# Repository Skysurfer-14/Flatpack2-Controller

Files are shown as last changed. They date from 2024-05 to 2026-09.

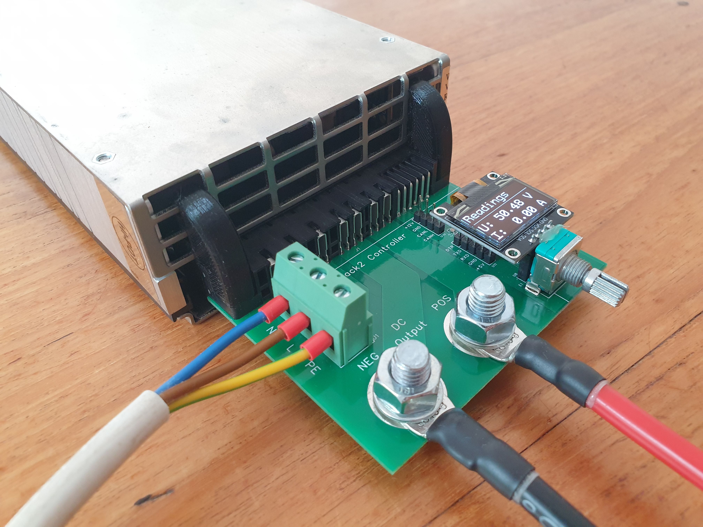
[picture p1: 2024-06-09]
docs/flatpack2-controller.jpg

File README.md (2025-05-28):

## Flatpack2 Controller ##
Connection board with controller, display and rotary encoder for controlling an Eltek Flatpack2 HE 48V/3000W power supply.
The Arduino program of the controller is maintained in this repository. Extensions and improvements are welcome!
flatpack2-controller
### Quick guide ###
- voltage and current are displayed after switching on (readings)
- to protect the OLED display, it is switched off after 60s if the rotary encoder is not used. It can be switched on again by pressing the Rotary Encoder.
- briefly pressing the Rotary Encoder switches the OLED display to the settings for the voltage. Turning the rotary encoder increases or decreases the voltage. A short press switches to the settings for the current. If the rotary encoder is pressed and held, the set value is also written to the non-volatile memory of the controller. 
- in the settings for the current, the maximum current can be increased or decreased by turning the rotary encoder. A short press switches to the readings. If the rotary encoder is pressed and held, the set value is also written to the non-volatile memory of the controller.

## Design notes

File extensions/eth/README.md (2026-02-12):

## **1. nano_skript.txt – Arduino Nano Controller**

Dieses Programm läuft auf einem **Arduino Nano** und dient als **Steuereinheit für ein Flatpack2-Netzteil** (PSU = Power Supply Unit). Der Nano ist das zentrale Steuergerät mit folgenden Hauptaufgaben:

### Kernfunktionen:
- **Lokale Bedienung**: Über einen Drehencoder (Rotary Encoder) und ein OLED-Display können Spannung und Strom direkt am Gerät eingestellt werden
- **I2C-Kommunikation mit PSU**: Der Nano kommuniziert über I2C mit dem Flatpack2-Netzteil, um:
  - Sollwerte (Spannung, Strom) zu setzen
  - Messwerte (aktuelle Spannung, Strom, Temperaturen) auszulesen
  - Das Netzteil ein-/auszuschalten
  - Statuswerte zu überwachen

- **UART-Kommunikation**: Der Nano fungiert als "Slave" und kann über die serielle Schnittstelle (38400 Baud) von einem übergeordneten System (WT32) ferngesteuert werden
- **Dual-Modus**: Das System kann sowohl **autonom** (nur mit Nano) als auch **ferngesteuert** (über WT32) betrieben werden. Das Display zeigt an, ob ein Master-Gerät (z.B. "Cerbo") verbunden ist

### Besondere Features:
- Speicherung der Einstellungen im EEPROM
- Heartbeat-Mechanismus zur Verbindungsüberwachung
- CRC-gesicherte Kommunikation
- Display-Timeout zur Schonung

---

## **2. wt32-eth-skript.txt – WT32-ETH01 Webserver**

Dieses Programm läuft auf einem **WT32-ETH01** (ESP32 mit Ethernet) und dient als **Netzwerk-Gateway und Webinterface** für das Flatpack2-System:

### Kernfunktionen:
- **Web-Interface**: Stellt ein modernes HTML-Dashboard bereit, über das das Netzteil per Browser gesteuert werden kann
- **UART-Master**: Kommuniziert über Serial2 mit dem Nano und sendet Befehle (Spannung/Strom setzen, Ein/Aus schalten)
- **Ethernet/WiFi-Anbindung**: Ermöglicht Fernzugriff auf das System (feste IP: 192.168.1.234)
- **OTA-Updates**: Das Programm kann über das Netzwerk aktualisiert werden (Over-The-Air)

### API-Endpunkte:
- `/values` – Liefert aktuelle Messwerte und Status als JSON
- `/set_voltage?voltage=XX` – Setzt die Sollspannung
- `/set_current?current=XX` – Setzt den Sollstrom
- `/cmd?c=on|off` – Schaltet das Netzteil ein/aus

### Statusüberwachung:
- Erkennt, ob der Nano verbunden ist (Timeout: 15 Sekunden)
- Zeigt Gesundheitsstatus an (OK / WARN / FAULT)
- Überwacht Temperaturen und Statusbits des Netzteils

---

## **Zusammenspiel der beiden Systeme:**

```
[Flatpack2 PSU] ←I2C→ [Arduino Nano] ←UART→ [WT32-ETH01] ←Ethernet/WiFi→ [Browser/Victron Cerbo]
                         ↓
                  [Drehencoder + OLED]
```

Der **Nano** ist die direkte Hardwareschnittstelle zum Netzteil und kann eigenständig arbeiten. Der **WT32** erweitert das System um Netzwerkfunktionen und ein komfortables Webinterface, bleibt aber optional – der Nano funktioniert auch ohne ihn.

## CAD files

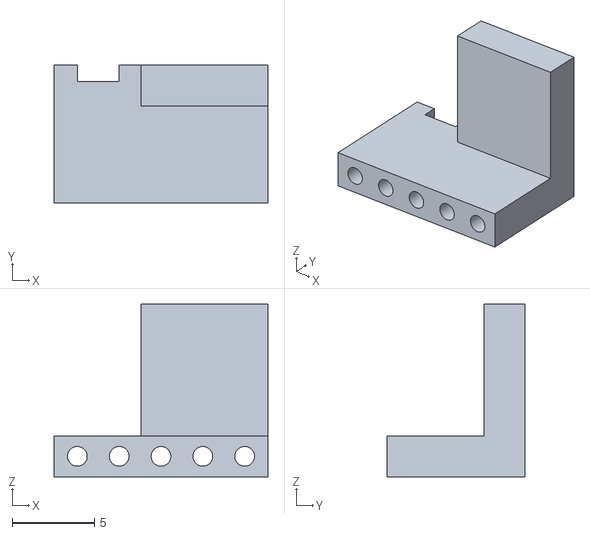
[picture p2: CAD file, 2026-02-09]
mechanic/DisplaySupport.stl
13.0 x 8.40 x 10.5

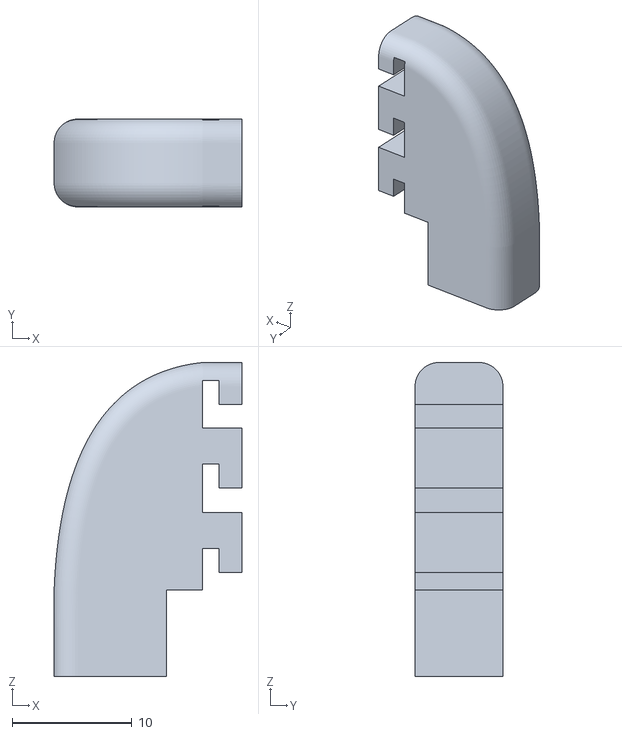
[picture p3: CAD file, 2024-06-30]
mechanic/Halteklammer Flatpack v2.stl
15.7 x 7.35 x 26.2

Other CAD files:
mechanic/DisplaySupport.f3d
mechanic/Halteklammer Flatpack v2.f3d

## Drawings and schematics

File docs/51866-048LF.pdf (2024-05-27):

PDS: Rev :B | STATUS:Released | Printed: Aug 14, 2013 Datasheet.Live

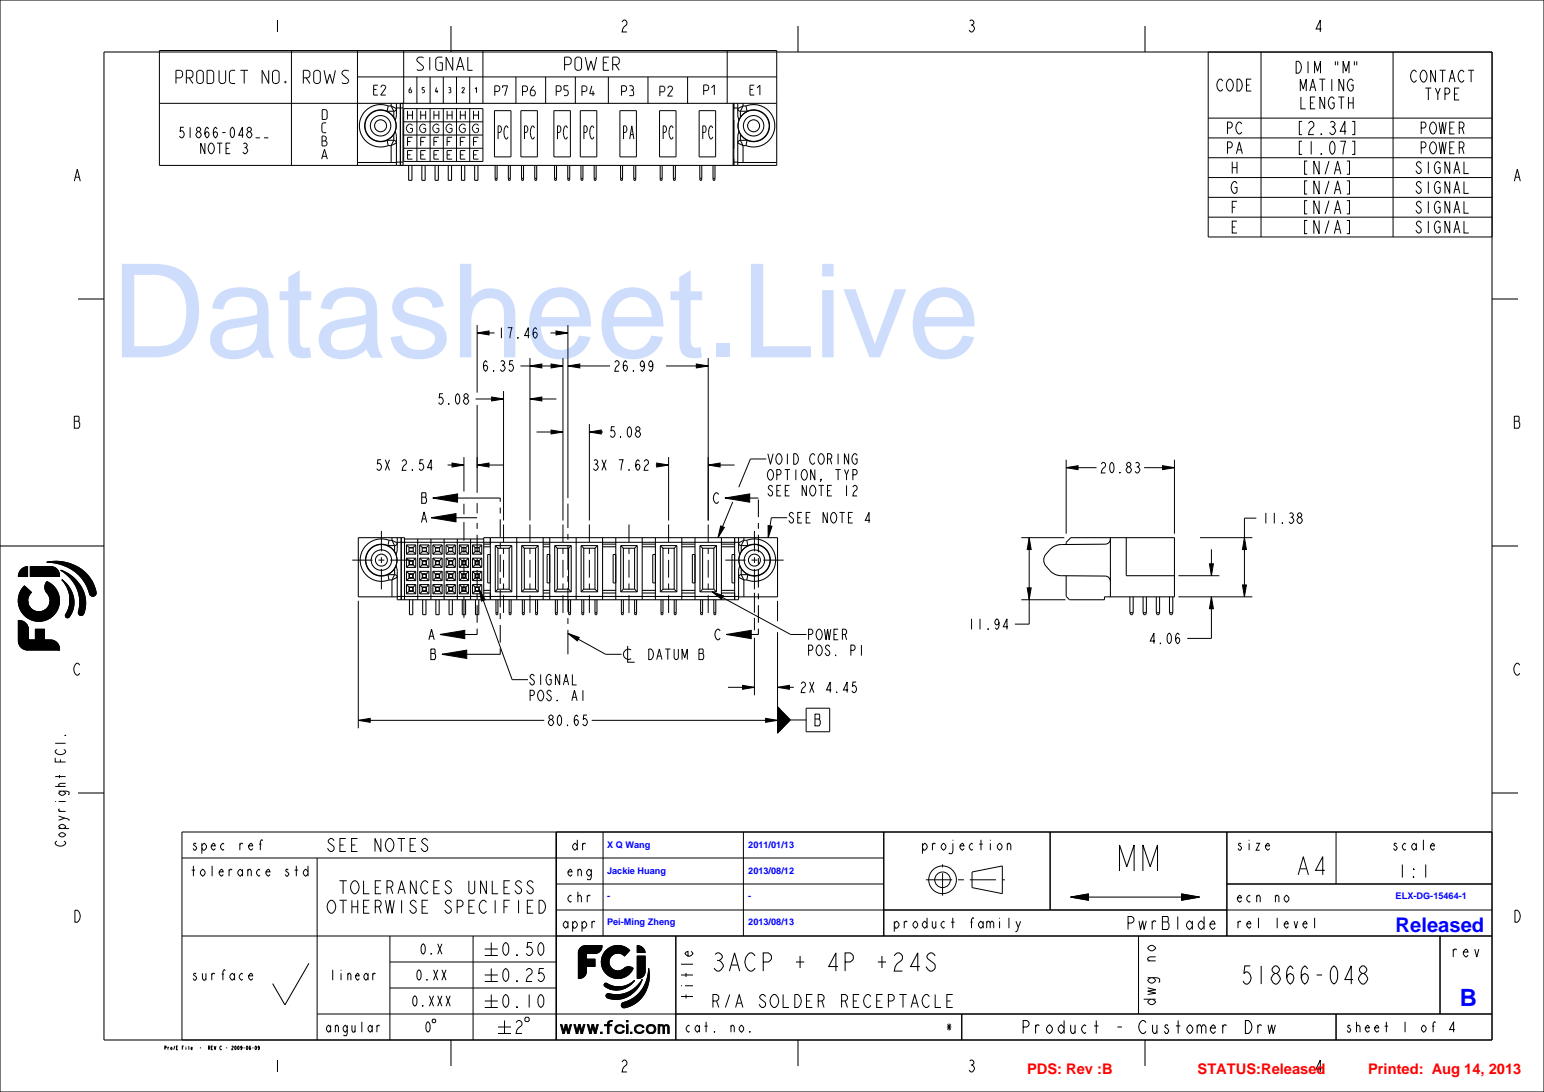
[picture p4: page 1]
Jackie Huang; X Q Wang; ELX-DG-15464-1 Released

Pei-Ming Zheng

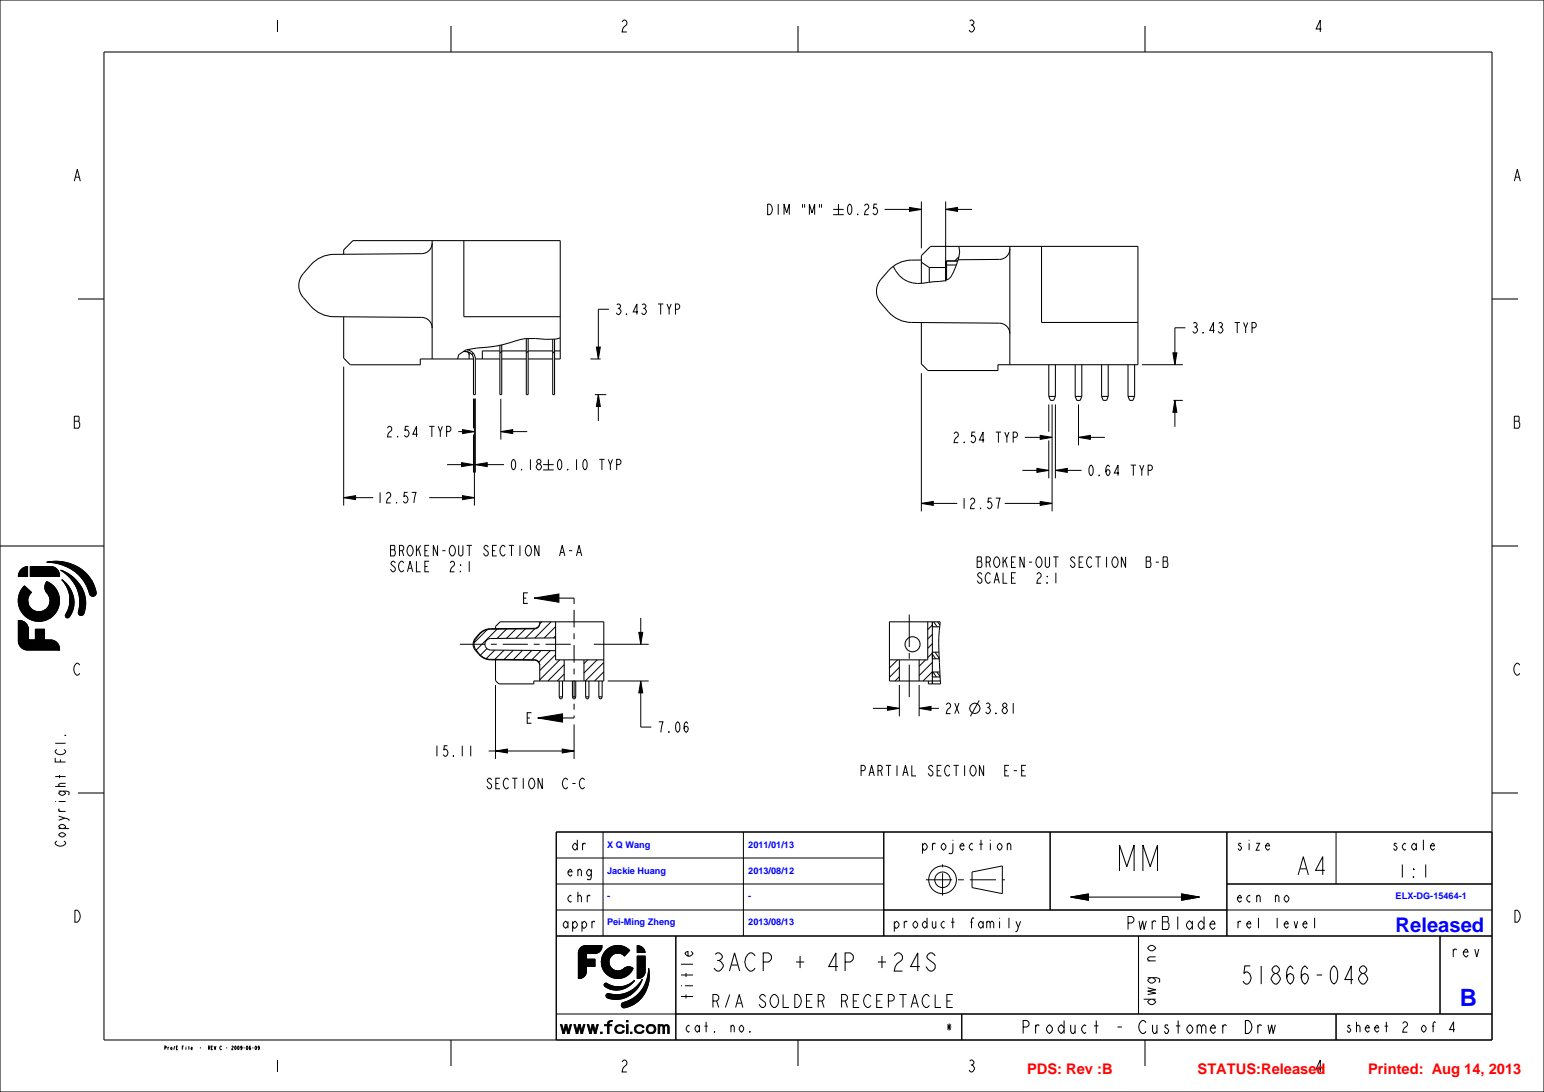
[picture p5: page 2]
Jackie Huang; X Q Wang; ELX-DG-15464-1 Released; PDS: Rev :B; STATUS:Released; Printed: Aug 14, 2013

Pei-Ming Zheng

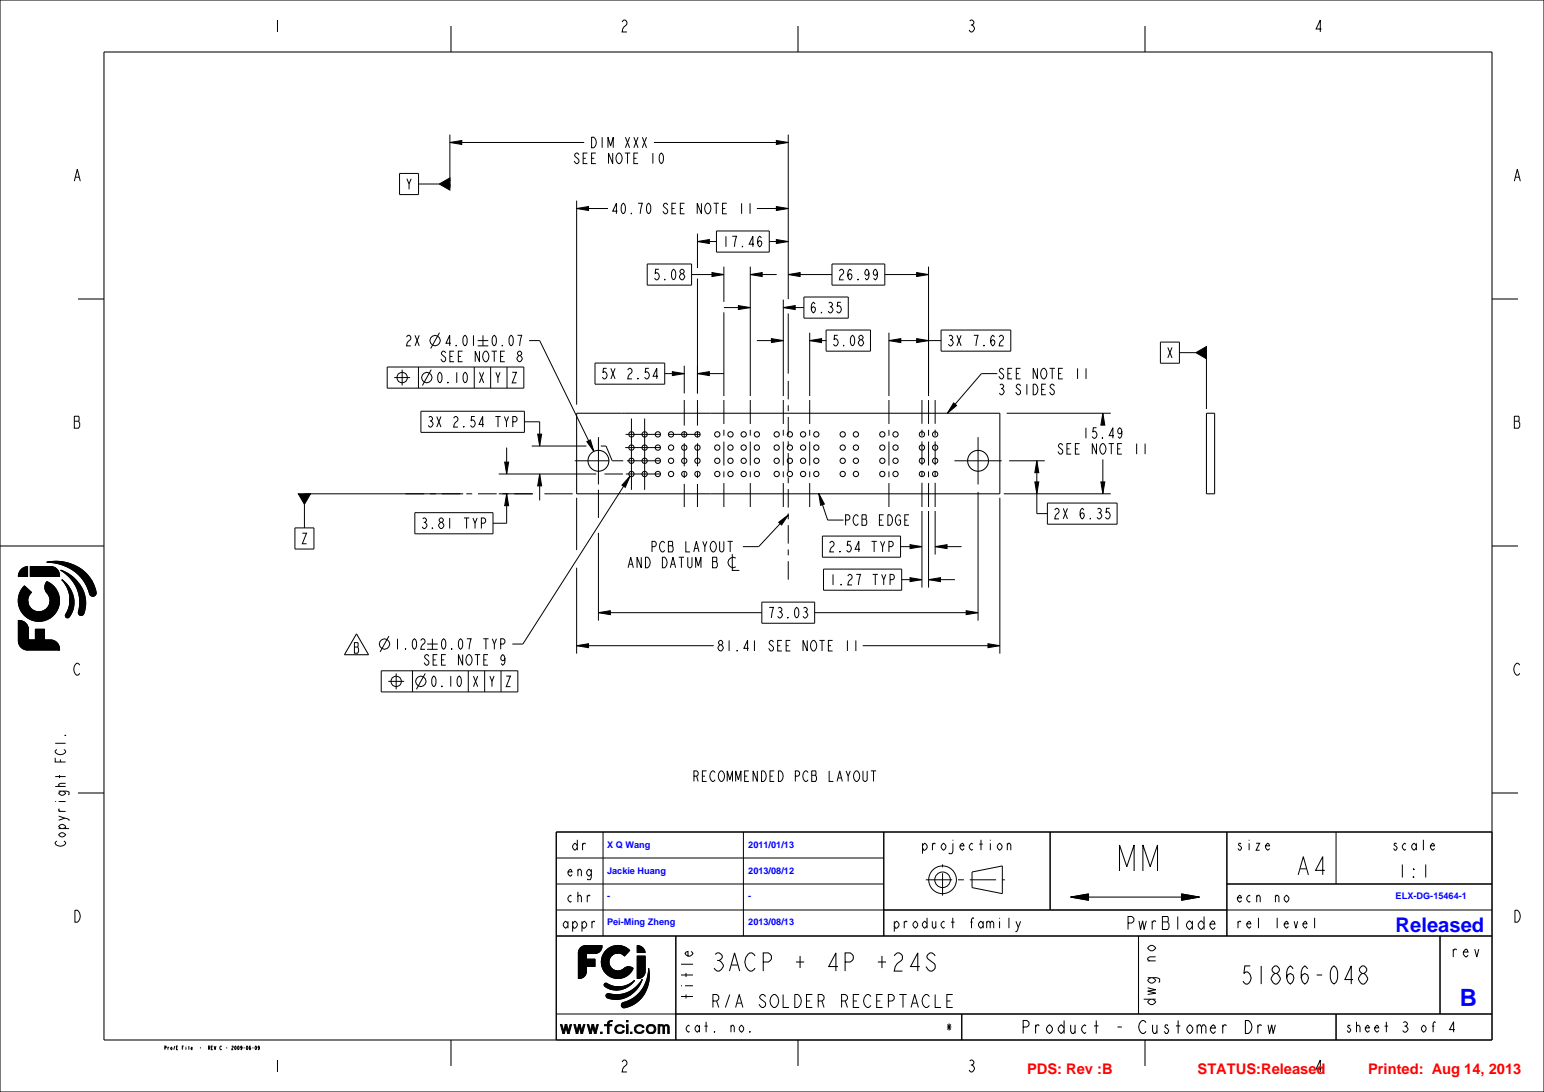
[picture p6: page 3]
Jackie Huang; X Q Wang; ELX-DG-15464-1 Released

Pei-Ming Zheng

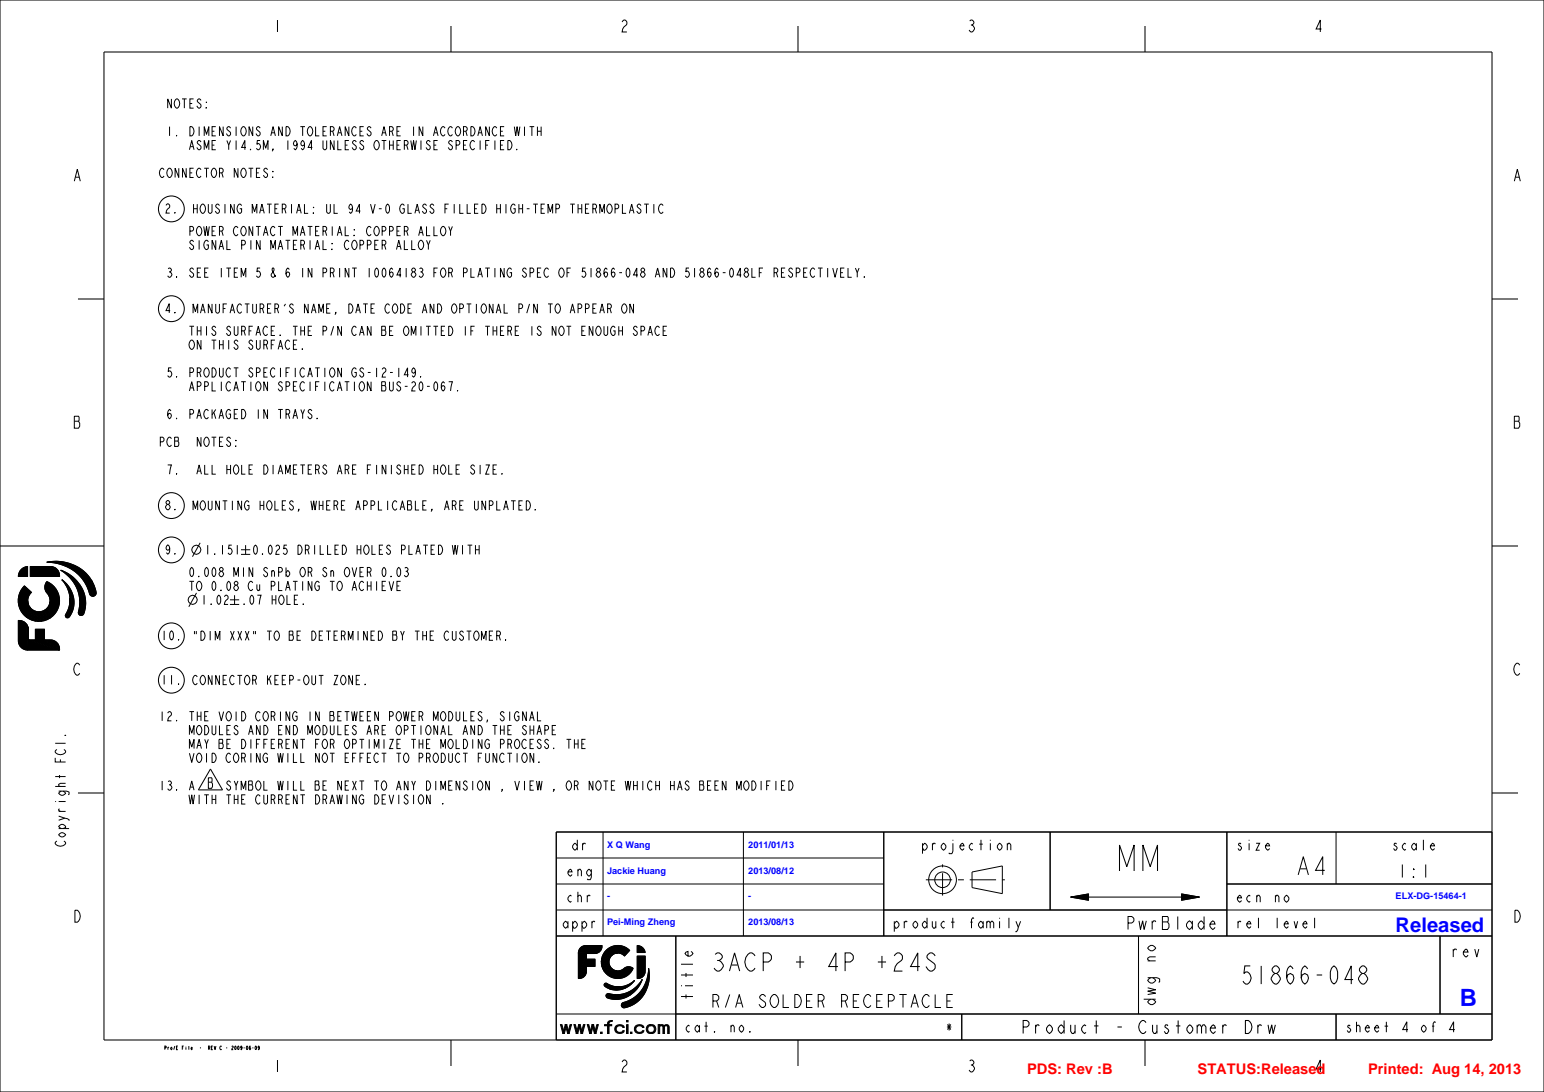
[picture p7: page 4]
Jackie Huang; X Q Wang; ELX-DG-15464-1 Released

Pei-Ming Zheng

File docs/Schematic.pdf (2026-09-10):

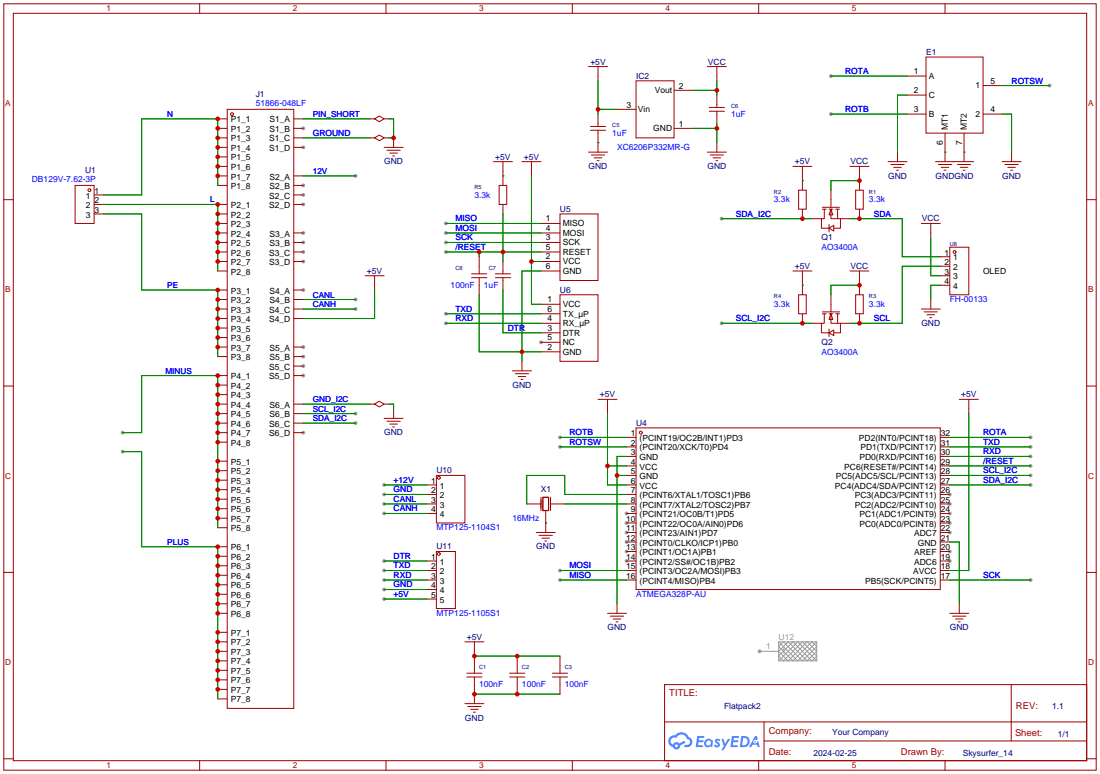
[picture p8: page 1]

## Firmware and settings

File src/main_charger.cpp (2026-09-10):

#include <Arduino.h>
#include <RotaryEncoder.h>
#include <Wire.h>
#include <SPI.h>
#include <U8g2lib.h>
#include <EEPROM.h>

/*
Todo:
- COMM_STAT vom PSU hat immer Bit1 gesetzt, sollte aber nicht gesetzt sein. Evtl. CRC8-Fehler?

*/

// The complete list is available here: https://github.com/olikraus/u8g2/wiki/u8g2setupcpp
// Please update the pin numbers according to your setup. Use U8X8_PIN_NONE if the reset pin is not connected
U8G2_SSD1306_128X64_NONAME_2_HW_I2C u8g2(U8G2_R2, /* reset=*/ U8X8_PIN_NONE);

#define ROTA  2
#define ROTB  3
#define ROTSW 4

#define PSU_WRITE_ADDR  0x00
#define PSU_READ_ADDR   0x0F

// PSU RAM
// PSU Status, Offset 0x00
#define PSU_STATUS          0x00  // Read Only
#define PSU_STAT_DC_ON          0x0001  // 1 = DC/DC enabled
#define PSU_STAT_BOOST_OK       0x0002  // 1 = Boost Voltage OK
#define PSU_STAT_AC_OK          0x0004  // 1 = AC input voltage OK
#define PSU_STAT_HVSD           0x0008  // 1 = Output shut down due to hi-voltage
#define PSU_STAT_FAN_FAIL       0x0010  // 1 = Fan failure
#define PSU_STAT_INT_TEMP       0x0040  // 1 = Heatsink over temperature alarm
#define PSU_STAT_ILIM           0x0080  // 1 = Current limit
#define PSU_STAT_UV_ALARM       0x0100  // 1 = Output Voltage below UV alarm threshold
#define PSU_STAT_UVSD           0x0200  // 1 = Output shut down due to lo-voltage
#define PSU_STAT_DC_ENABLE      0x0800  // 1 = DC enable asserted
#define PSU_STAT_REMOTE_OFF     0x1000  // 1 = Shutdown due to I2C remote off command     
#define PSU_STAT_MOD_DISABLE    0x2000  // 1 = Shutdown due to MOD_DISABLE input  
#define PSU_STAT_SHORT_PIN      0x4000  // 1 = Shutdown due to short pin transition    

// PSU Command, Offset 0x02
#define PSU_COMMAND         0x02  // Write
#define PSU_CMD_ON              0x02  // 1 = Turn on Rectifier
#define PSU_CMD_OFF             0x04  // 1 = Turn off Rectifier
#define PSU_CMD_ALARM_ON        0x08  // 1 = Enable Latent DC Failure Alarm
#define PSU_CMD_ALARM_OFF       0x10  // 1 = Disable Latent DC Failure Alarm

#define PSU_LOCATION        0x03  // RO Number that identifies device location in a shelf. (Hi-Nibble = Group type Lo-Nibble = Lo-Nibble of I2C Address)
#define PSU_TEMP_SEC_OR     0x04  // RO Output OR-ing FET temperature in degrees C Range 0C to +116C, 255=short, +127=open
#define PSU_TEMP_SEC_DIODES 0x05  // RO DC/DC output diode temperature in degrees C Range 0C to +116C, 255=short, 127=open
#define PSU_MEASURE_VOUT    0x06  // RO Output Voltage in Volts x 100
#define PSU_MEASURE_IOUT    0x08  // RO Output Current in Amps x 100
#define PSU_SETPOINT_ILIMIT 0x0A  // RW Current Limit Set Point in Amps x 100
#define PSU_SETPOINT_VOUT   0x0C  // RW Output Voltage Set Point in Volts x 100
#define PSU_SETPOINT_HVSD   0x0E  // RW Unit level High Voltage Shut Down Set Point in Volts x 100
#define PSU_SETPOINT_FAN    0x10  // RO Fan period, 38 - Low, 27 – Med, 1B – High, read only

// PSU EEPROM
#define PSU_SERIAL_NUMBER   0x42  // RO uchar[12] Device serial number as an array of ASCII characters
#define PSU_MODEL_NUMBER    0x4E  // RO uchar[8] Device model number as an array of ASCII characters
#define PSU_VSET_DEFAULT    0x72  // RW Power-up value for voltage setpoint
#define PSU_ISET_DEFAULT    0x74  // RW Power-up default for current limit setpoint
#define PSU_HVSD_DEFAULT    0x76  // RW Power-up default for HVSD setpoint

#define DISPLAY_TIMEOUT     60000 // OLED Protection Timeout (ms)
#define PSU_VSET_MAX        5800  // Maximum Voltage Setting (Volt * 100)
#define PSU_VSET_MIN        4320  // Minimum Voltage Setting (Volt * 100)
#define PSU_V_RELOAD_DEFAULT 4800 // Default restart voltage (Volt * 100)
#define PSU_ISET_MAX        6250  // Maximum Current Setting (Ampere * 100)
#define PSU_ISET_MIN        0000  // Minimum Current Setting (Ampere * 100)
#define CV_CHARGING_TIMEOUT (30UL * 60UL * 1000UL)

// Charger defines
#define OC_CURRENT_FACTOR   2     // Threshold factor for OC-Error
#define OC_ERROR_ENABLED    0     // Enable OC-Error

// Prozessor-EEPROM
struct nonVolatileStruct
{
  uint16_t voltage;
  uint16_t current;
  uint16_t highvoltage;
  uint16_t reloadVoltage;
  uint8_t chargeMode;
};

nonVolatileStruct nonVolatile;

enum ChargeMode : uint8_t
{
  single_charge,
  cycle_charge
};

uint16_t actualReadVoltage = 0;
uint16_t actualReadCurrent = 0;
uint16_t actualSetVoltage = 0;
uint16_t actualSetCurrent = 0;

typedef enum {
  wait_for_battery,
  ramp_up,
  cc_charging,
  cv_charging,
  wait_for_reload,
  charging_done,
  wait_for_nobattery,
  oc_error,
  nc_error,
  setting_u,
  setting_i,
  setting_reload,
  setting_charge_mode,
  save_dialog,
  save
} State_type;

State_type state = wait_for_battery;

bool psuDcOn = true;
bool displayOn = true;

// Setup a RotaryEncoder 
RotaryEncoder encoder(ROTB, ROTA, RotaryEncoder::LatchMode::FOUR3);

const unsigned long longPressThreshold = 1000; // Schwelle für einen langen Tastendruck in Millisekunden

unsigned long pressStartTime = 0;
bool isPressed = false;
bool wasLongPress = false;
bool wasPressed = false;

bool wasLongPressReported = false;

// a global variables to hold the last position
static int lastPos = 0;

long timeButtonPressed;
unsigned long cvChargingStartTime = 0;

// Prototypes
void scan_i2c ();
uint8_t crc82(uint8_t *p, uint8_t len);
void write8Psu(uint8_t addr, uint8_t offs, uint8_t value);
void write16Psu(uint8_t addr, uint8_t offs, uint16_t value);
uint8_t readPsu(uint8_t addr, uint8_t len, uint8_t offs);
int leseDigitaleingang(int pin, int &vorherigerZustand);

uint8_t in_buffer[20];
uint8_t result;


// This interrupt routine will be called on any change of one of the input signals
void checkPosition()
{
  encoder.tick(); // just call tick() to check the state.
}

/**
 * @brief Reads data from a power supply unit (PSU) over I2C.
 * 
 * This function communicates with a PSU via I2C to read a specified number
 * of bytes from a given address and offset. It calculates and verifies a CRC
 * to ensure data integrity. If a CRC error is detected, the appropriate bit is set
 * in the communication status.
 * 
 * @param addr The I2C address of the PSU.
 * @param len The number of data bytes to read from the PSU.
 * @param offs The offset from which to start reading data.
 * @return The communication status, with a bit set if a CRC error is detected.
 */
uint8_t readPsu(uint8_t addr, uint8_t len, uint8_t offs) 
{
  int i = 0;
  uint8_t comm_stat;

  uint8_t data[] = {addr, len, offs};
  uint8_t crc = crc82(data, sizeof(data));
  Wire.beginTransmission(addr);
  Wire.write(len);
  Wire.write(offs);
  Wire.write(crc);
  Wire.endTransmission(false);
  len += 3;
  Wire.requestFrom(addr, len);  // COMM_STAT + Daten + CRC16
  //Wire.requestFrom(addr, len+3, offs, len+3, true);
  comm_stat = Wire.read();  // COMM_STAT lesen 
  while (Wire.available())
  {
    in_buffer[i++] = Wire.read();
  }
  // CRC
  uint16_t crc16 = comm_stat;
  for (uint8_t i = 0; i < len; i++)
  {
    crc16 += in_buffer[i];
  }
  crc16 = ~crc16 + 1;

  if ((in_buffer[len] != (crc16 & 0xFF)) || (in_buffer[len+1] != (crc16 >> 8)))
  {
    comm_stat |= 0x10;  // CRC error
  }

  return comm_stat;
}

/**
 * @brief displayActual: Display actual values of the power supply
 * @param sTitle The title string to be displayed on the first line of the display
 *
 * This function reads the actual values of the output voltage and current from the
 * power supply and displays them on the display. The title string is displayed on
 * the first line. The values are displayed with two decimal places on the second and
 * third line.
 */
void displayActual(const char* sTitle)
{
  float uValue, iValue;

  result = readPsu(PSU_READ_ADDR, 2, PSU_MEASURE_VOUT);
  uValue = (float)(in_buffer[0] + (in_buffer[1] << 8))/100.0;
  result = readPsu(PSU_READ_ADDR, 2, PSU_MEASURE_IOUT);
  iValue = (float)(in_buffer[0] + (in_buffer[1] << 8))/100.0;

  u8g2.firstPage();
  do {
    u8g2.setFont(u8g2_font_profont22_mr);
//    
    u8g2.drawStr(0,14,sTitle);
    u8g2.drawHLine(0,20,128);

    u8g2.setCursor(0,41);
    u8g2.print("U: ");
    if (uValue < 10.0) u8g2.print(" ");  // Führendes Leerzeichen, falls erforderlich
    u8g2.print(uValue);
    u8g2.print(" V ");

    u8g2.setCursor(0,63);
    u8g2.print("I: ");
    if (iValue < 10.0) u8g2.print(" ");  // Führendes Leerzeichen, falls erforderlich
    u8g2.print(iValue);
    u8g2.print(" A ");
  } while ( u8g2.nextPage() );
}


/**
 * Displays the settings for voltage and current on the screen.
 * 
 * This function renders the voltage (U) and current (I) settings 
 * using the u8g2 library. The displayed values are converted from 
 * integer to float by dividing by 100.0. It highlights the field 
 * currently being edited, as indicated by the lineEdit parameter.
 *
 * @param lineEdit Indicates which line (1 for voltage, 2 for current) 
 *                 is being edited. The corresponding line will be 
 *                 highlighted.
 * @param u        The voltage value to be displayed, scaled by 100.
 * @param i        The current value to be displayed, scaled by 100.
 */
void displaySetting(uint8_t lineEdit, uint16_t u, uint16_t i)
{
  float uValue, iValue;

  uValue = u / 100.0;
  iValue = i / 100.0;

  u8g2.firstPage();
  do {
    u8g2.setFont(u8g2_font_profont22_mr);
    u8g2.drawStr(0,14,"Settings");
    u8g2.drawHLine(0,20,128);
    u8g2.setFontMode(0);
    
    u8g2.setCursor(0,41);
    u8g2.print("U: ");
    u8g2.setDrawColor((lineEdit == 1) ? 0 : 1);
    if (uValue < 10.0) u8g2.print(" ");  // Führendes Leerzeichen, falls erforderlich
    u8g2.print(uValue);
    u8g2.setDrawColor(1);
    u8g2.print(" V ");

    u8g2.setCursor(0,63);
    u8g2.print("I: ");
    u8g2.setDrawColor((lineEdit == 2) ? 0 : 1);
    if (iValue < 10.0) u8g2.print(" ");  // Führendes Leerzeichen, falls erforderlich
    u8g2.print(iValue);
    u8g2.setDrawColor(1);
    u8g2.print(" A ");
  } while ( u8g2.nextPage() );
}

void displayReloadAndChargeMode(uint8_t lineEdit, uint16_t reloadVoltage, uint8_t chargeMode)
{
  float reloadValue = reloadVoltage / 100.0;

  u8g2.firstPage();
  do {
    u8g2.setFont(u8g2_font_profont22_mr);
    u8g2.drawStr(0,14,"Settings");
    u8g2.drawHLine(0,20,128);
    u8g2.setFontMode(0);

    u8g2.setCursor(0,41);
    u8g2.print("R: ");
    u8g2.setDrawColor((lineEdit == 1) ? 0 : 1);
    if (reloadValue < 10.0) u8g2.print(" ");
    u8g2.print(reloadValue);
    u8g2.setDrawColor(1);
    u8g2.print(" V ");

    u8g2.setCursor(0,63);
    u8g2.print("C: ");
    u8g2.setDrawColor((lineEdit == 2) ? 0 : 1);
    u8g2.print(chargeMode == cycle_charge ? "Multi" : "Single");
    u8g2.setDrawColor(1);
  } while ( u8g2.nextPage() );
}

/**
 * @brief Setup function, called once at startup.
 *
 * Initialize I2C interface and U8G2 library, display the title string
 * and wait until the FP2-Charger has finished its startup sequence.
 * Then, read the non-volatile values from EEPROM and initialize the
 * power supply with these values.
 */
void setup() {
  Wire.begin();
  Serial.begin(115200);

  pinMode(ROTSW, INPUT_PULLUP);

  // register interrupt routine
  attachInterrupt(digitalPinToInterrupt(ROTB) , checkPosition, CHANGE);
  attachInterrupt(digitalPinToInterrupt(ROTA) , checkPosition, CHANGE);

//  scan_i2c ();

  u8g2.setBusClock(50000);
  u8g2.begin();
  u8g2.firstPage();
  do {
    u8g2.setFont(u8g2_font_profont22_mr);
    u8g2.drawStr(0,14,"FP2-Charger");
    u8g2.setFont(u8g2_font_profont17_mr);
    u8g2.drawStr(10,42,"Version 2.00");
  } while ( u8g2.nextPage() );
  delay(1000);                          // anpassen an die Startup-Zeit des FP2

  EEPROM.get(0, nonVolatile);
  //nonVolatile.voltage = 20000;      // erneute Initialisierung der EEPROM-Struktur
  if (nonVolatile.voltage > 10000)    // Defaultwerte schreiben, wenn EEPROM neu
  {
    nonVolatile.voltage = 4800;
    nonVolatile.current = 6250;
    nonVolatile.highvoltage = 5900;
    nonVolatile.reloadVoltage = PSU_V_RELOAD_DEFAULT;
    nonVolatile.chargeMode = single_charge;
    EEPROM.put(0, nonVolatile);
  }
  if (nonVolatile.reloadVoltage < PSU_VSET_MIN || nonVolatile.reloadVoltage > nonVolatile.voltage)
  {
    nonVolatile.reloadVoltage = min(PSU_V_RELOAD_DEFAULT, nonVolatile.voltage);
    EEPROM.put(0, nonVolatile);
  }
  if (nonVolatile.chargeMode > cycle_charge)
  {
    nonVolatile.chargeMode = single_charge;
    EEPROM.put(0, nonVolatile);
  }

  // PSU auf Default-Werte einstellen
//  write16Psu(PSU_WRITE_ADDR, PSU_SETPOINT_VOUT, nonVolatile.voltage);
  write16Psu(PSU_WRITE_ADDR, PSU_SETPOINT_ILIMIT, nonVolatile.current);
  write16Psu(PSU_WRITE_ADDR, PSU_SETPOINT_HVSD, nonVolatile.highvoltage);
  // Spannung erst mal ausschalten
  write8Psu(PSU_WRITE_ADDR, PSU_COMMAND, PSU_CMD_OFF);

  timeButtonPressed = millis();
}


/**
 * loop(): The main loop of the program. It checks the state of the rotary encoder
 * and the button. Depending on the state, it either displays the actual values
 * of the power supply or allows the user to enter new values. 
 * The states are:
 * - wait_for_battery: wait for the battery to be connected
 * - ramp_up: ramp up the voltage to the set value
 * - cc_charging: keep the voltage at the set value and regulate the current
 * - cv_charging: keep the voltage at the set value and regulate the current, but
 *                with a lower current limit
 * - wait_for_reload: wait until the battery voltage falls to the recharge threshold
 * - wait_for_nobattery: wait for the battery to be disconnected
 * - oc_error: display an overcurrent error
 * - nc_error: display a no connection error
 * - setting_u: allow the user to set the voltage
 * - setting_i: allow the user to set the current
 * - setting_reload: allow the user to set the reload voltage
 * - setting_charge_mode: allow the user to select single or cycle charge
 */
void loop() {
  int buttonState = digitalRead(ROTSW);

  if (buttonState == LOW) 
  {
    timeButtonPressed = millis();

    if (!isPressed) 
    {
      // Taste wurde neu gedrückt
      pressStartTime = millis(); // Startzeit messen
      isPressed = true; // Status aktualisieren
      wasLongPressReported = false; // Rücksetzen der langen Tastendruck-Meldung
    } 
    else if (!wasLongPressReported && (millis() - pressStartTime >= longPressThreshold)) 
    {
      // Langer Tastendruck wird gemeldet, während die Taste noch gedrückt ist
      Serial.println("Langer Tastendruck erkannt.");
      wasLongPressReported = true; // Verhindert weitere Meldungen, solange die Taste gedrückt bleibt
      wasPressed = true;
    }
  } 
  else if (buttonState == HIGH && isPressed) 
  {
    // Taste wurde losgelassen
    isPressed = false; // Status zurücksetzen

    if (!wasLongPressReported) 
    {
      // Es war ein kurzer Tastendruck, weil kein langer Tastendruck gemeldet wurde
      Serial.println("Kurzer Tastendruck erkannt.");
      wasPressed = true;
    }
  }

  encoder.tick(); // just call tick() to check the state.

  int newPos = encoder.getPosition();

  if (lastPos != newPos) 
  {
    if (encoder.getMillisBetweenRotations() < 50) 
    {
      newPos = lastPos + 10 * (newPos - lastPos);
      encoder.setPosition(newPos);
    }
    timeButtonPressed = millis();
    Serial.print("pos:");
    Serial.print(newPos);
    Serial.print(" dir:");
    Serial.println((int)(encoder.getDirection()));
    lastPos = newPos;
  } // if


  switch (state)
  {
    case wait_for_battery:
      // Display nach gewisser Zeit ausschalten
      if ((millis() - timeButtonPressed) > DISPLAY_TIMEOUT)
      {
        if (displayOn)
        {
          // Display off
          u8g2.setPowerSave(1);
          displayOn = false;
          Serial.println("Display off");
        }
      }
      else
      {
        if (!displayOn)
        {
          u8g2.setPowerSave(0);
          displayOn = true;
          Serial.println("Display on");
        }

        // OLED aktualisieren
        displayActual("Connect");

        // Tastendruck
        if (wasPressed) 
        {
          if (wasLongPressReported)
          {
            encoder.setPosition(nonVolatile.voltage);
            lastPos = encoder.getPosition();
            state = setting_u;
          }
          // Bei kurzem Tastendruck in die Settings
          else
          {
            encoder.setPosition(nonVolatile.voltage);
            lastPos = encoder.getPosition();
            state = setting_u;
          }
          wasPressed = false;  
        }
      }

      // Spannung lesen
      result = readPsu(PSU_READ_ADDR, 2, PSU_MEASURE_VOUT);
      actualReadVoltage = in_buffer[0] + (in_buffer[1] << 8);
      // Akku angeschlossen?
      if (actualReadVoltage > PSU_VSET_MIN)
      {
        // Stabile Spannung abwarten
        delay(250);
        result = readPsu(PSU_READ_ADDR, 2, PSU_MEASURE_VOUT);
        actualReadVoltage = in_buffer[0] + (in_buffer[1] << 8); 
        // Akku angeschlossen?
        if (actualReadVoltage > PSU_VSET_MIN)
        { 
          actualSetVoltage = actualReadVoltage;
          actualSetCurrent = nonVolatile.current;
          write16Psu(PSU_WRITE_ADDR, PSU_SETPOINT_VOUT, actualSetVoltage); // Spannung setzen (RAM)
          write8Psu(PSU_WRITE_ADDR, PSU_COMMAND, PSU_CMD_ON);
          state = ramp_up;
        }
      }
      break;

    case ramp_up:
      // display
      displayActual("Ramp_up");
      // Strom lesen
      result = readPsu(PSU_READ_ADDR, 2, PSU_MEASURE_IOUT);
      actualReadCurrent = in_buffer[0] + (in_buffer[1] << 8);
      // Überstrom-Überwachung
      if (OC_ERROR_ENABLED && (actualReadCurrent > actualSetCurrent * OC_CURRENT_FACTOR))
      {
        write8Psu(PSU_WRITE_ADDR, PSU_COMMAND, PSU_CMD_OFF);
        state = oc_error;
        break;
      }
      if (actualReadCurrent < actualSetCurrent)
      {
        // Spannung grossschrittig erhöhen (0,1V)
        actualSetVoltage += 10;
        write16Psu(PSU_WRITE_ADDR, PSU_SETPOINT_VOUT, actualSetVoltage); // Spannung setzen (RAM)   
        delay(250);     
      }
      else
      {
        state = cc_charging;
      }
      break;

    case cc_charging:
      // display
      displayActual("CC-Charg.");
      // Strom lesen
      result = readPsu(PSU_READ_ADDR, 2, PSU_MEASURE_IOUT);
      actualReadCurrent = in_buffer[0] + (in_buffer[1] << 8);
      // Überstrom-Überwachung
      if (OC_ERROR_ENABLED && (actualReadCurrent > actualSetCurrent * 2))
      {
        write8Psu(PSU_WRITE_ADDR, PSU_COMMAND, PSU_CMD_OFF);
        state = oc_error;
        break;
      }
      // Überwachung auf Unterbrechung
      if (actualReadCurrent == 0)
      {
        write8Psu(PSU_WRITE_ADDR, PSU_COMMAND, PSU_CMD_OFF);
        state = nc_error;
        break;
      }
      if (actualReadCurrent < actualSetCurrent)
      {
        // Spannung kleinschrittig erhöhen (0,01V)
        actualSetVoltage++;    
      }
      else
      {
        // Spannung kleinschrittig verringern (0,01V)
        actualSetVoltage--;
      }
      write16Psu(PSU_WRITE_ADDR, PSU_SETPOINT_VOUT, actualSetVoltage); // Spannung setzen (RAM)   
      delay(250); 
      // Ladeschlussspannung erreicht?
      if (actualSetVoltage >= nonVolatile.voltage)
      {
        write16Psu(PSU_WRITE_ADDR, PSU_SETPOINT_VOUT, nonVolatile.voltage); // Spannung setzen (RAM)   
        cvChargingStartTime = millis();
        state = cv_charging;
      }
      break;

    case cv_charging:
      // display
      displayActual("CV-Charg.");
      // Strom lesen
      result = readPsu(PSU_READ_ADDR, 2, PSU_MEASURE_IOUT);
      actualReadCurrent = in_buffer[0] + (in_buffer[1] << 8);
      // Überstrom-Überwachung
      if (OC_ERROR_ENABLED && (actualReadCurrent > actualSetCurrent * OC_CURRENT_FACTOR))
      {
        write8Psu(PSU_WRITE_ADDR, PSU_COMMAND, PSU_CMD_OFF);
        state = oc_error;
        break;
      }
      // CV-Charging beenden, sobald nur noch 1/10 des Ladestroms fliesst
      if (actualReadCurrent < actualSetCurrent / 10)
      {
        // PSU ausschalten
        write8Psu(PSU_WRITE_ADDR, PSU_COMMAND, PSU_CMD_OFF);  
        state = nonVolatile.chargeMode == cycle_charge ? wait_for_reload : wait_for_nobattery;
        break;
      }
      if (actualReadCurrent > uint16_t (actualSetCurrent * 1.5))
      {
        // zurück zur Stromregelung, wenn die Batteriespannung durch hohe Last wieder sinkt
        state = cc_charging;
      }
      if (millis() - cvChargingStartTime >= CV_CHARGING_TIMEOUT)
      {
        write8Psu(PSU_WRITE_ADDR, PSU_COMMAND, PSU_CMD_OFF);
        state = nonVolatile.chargeMode == cycle_charge ? wait_for_reload : wait_for_nobattery;
      }
      break;

    case wait_for_reload:
      // PSU ausgeschaltet lassen, bis die Batteriespannung wieder sinkt.
      displayActual("Wait Reload");
      result = readPsu(PSU_READ_ADDR, 2, PSU_MEASURE_VOUT);
      actualReadVoltage = in_buffer[0] + (in_buffer[1] << 8);
      if (actualReadVoltage <= nonVolatile.reloadVoltage)
      {
        actualSetVoltage = actualReadVoltage;
        actualSetCurrent = nonVolatile.current;
        write16Psu(PSU_WRITE_ADDR, PSU_SETPOINT_VOUT, actualSetVoltage);
        write8Psu(PSU_WRITE_ADDR, PSU_COMMAND, PSU_CMD_ON);
        state = ramp_up;
      }
      break;

    case wait_for_nobattery:
      // display
      displayActual("Ready");
      // Spannung lesen
      result = readPsu(PSU_READ_ADDR, 2, PSU_MEASURE_VOUT);
      actualReadVoltage = in_buffer[0] + (in_buffer[1] << 8);    
      if (actualReadVoltage < PSU_VSET_MIN)
      {
        delay(1000);
        state = wait_for_battery;
      }
      break;

    case oc_error:
      // display
      displayActual("OC-Error");
      break;

    case nc_error:
      // display
      displayActual("NC-Error");
      break;
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

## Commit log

2024-06-30 adding mechanic files
    [Halteklammer Flatpack v2.f3d, Halteklammer Flatpack v2.stl]
2024-07-22 Maximum Voltage set to 58V
2024-09-09 Dfault High Voltage Shut Down Set Point increased to 59V
2024-09-23 Basic Charger Code
2024-12-25 Add files via upload
    Schematic V1.1
2025-06-15 Update main_charger.cpp
    Reduced starting voltage
2025-08-24 Improved startup behavior with Flatpack2 Rev. 1.10
    Wait until PSU AC and BOOST are active, first disable voltage. Extension required for PSU Rev. 1.10
    FW version 1.10
2026-02-09 Add files via upload
    Support for the OLED display
    [DisplaySupport.stl]
2026-03-23 Add files via upload
    3D model of PCBA added
2026-09-10 Extensive updates to the charger firmware, now at version 2.00 Single and Multi Charging modes can be configured in the Settings For Multi Charging, the reload voltage can be specified in the setting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
